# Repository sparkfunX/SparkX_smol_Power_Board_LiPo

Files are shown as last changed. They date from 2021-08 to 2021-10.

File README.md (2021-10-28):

# SparkX smôl Power Board : LiPo

SparkX smôl Power Board : LiPo (SPX-18622) (https://www.sparkfun.com/products/18622)

[*SparkX smôl Power Board : LiPo (SPX-18622)*](https://www.sparkfun.com/products/18622)

A power board for smôl:
- LiPo battery connector and charger
- Fuel gauge
- ATtiny841 for intelligent power management

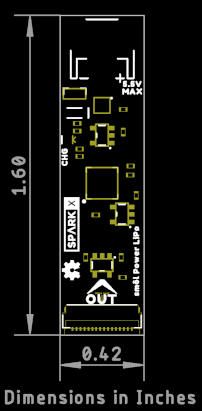
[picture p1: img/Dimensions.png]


## Repository Contents

- **/Documentation** - Datasheets etc.
- **/Hardware** - Eagle design files
- **LICENSE.md** contains the licence information

## Product Versions

- [SPX-18622](https://www.sparkfun.com/products/18622) - Original SparkX Release.

## License Information

This product is _**open source**_!

Please review the LICENSE.md file for license information.

If you have any questions or concerns on licensing, please contact technical support on our [SparkFun forums](https://forum.sparkfun.com/viewforum.php?f=123).

Distributed as-is; no warranty is given.

- Your friends at SparkFun.

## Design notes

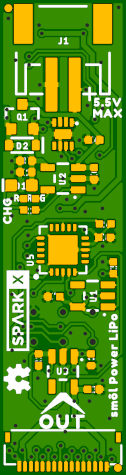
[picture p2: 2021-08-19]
img/Top.png

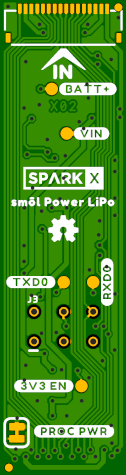
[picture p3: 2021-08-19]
img/Bottom.png

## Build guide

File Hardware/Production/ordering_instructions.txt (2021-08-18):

panel size, 193x137mm
PCB thickness, 0.8mm
number of layers, 2
soldermask color, Black
silkscreen color, White
oz copper, 1oz
finish, HASL lead free
stencils, top+bottom
pcs per panel, 48
min trace width, 0.1270mm / 0.0050in
min drill size, 0.3000mm / 0.0118in

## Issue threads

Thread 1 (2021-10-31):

Suggestions for the next board revision

PaulZC, 2021-10-31:
Based on these forum posts:

https://forum.sparkfun.com/viewtopic.php?p=229282#p229282
https://forum.sparkfun.com/viewtopic.php?p=229311#p229311

Add:
- Breakout pads for ATtiny RESET and INT0

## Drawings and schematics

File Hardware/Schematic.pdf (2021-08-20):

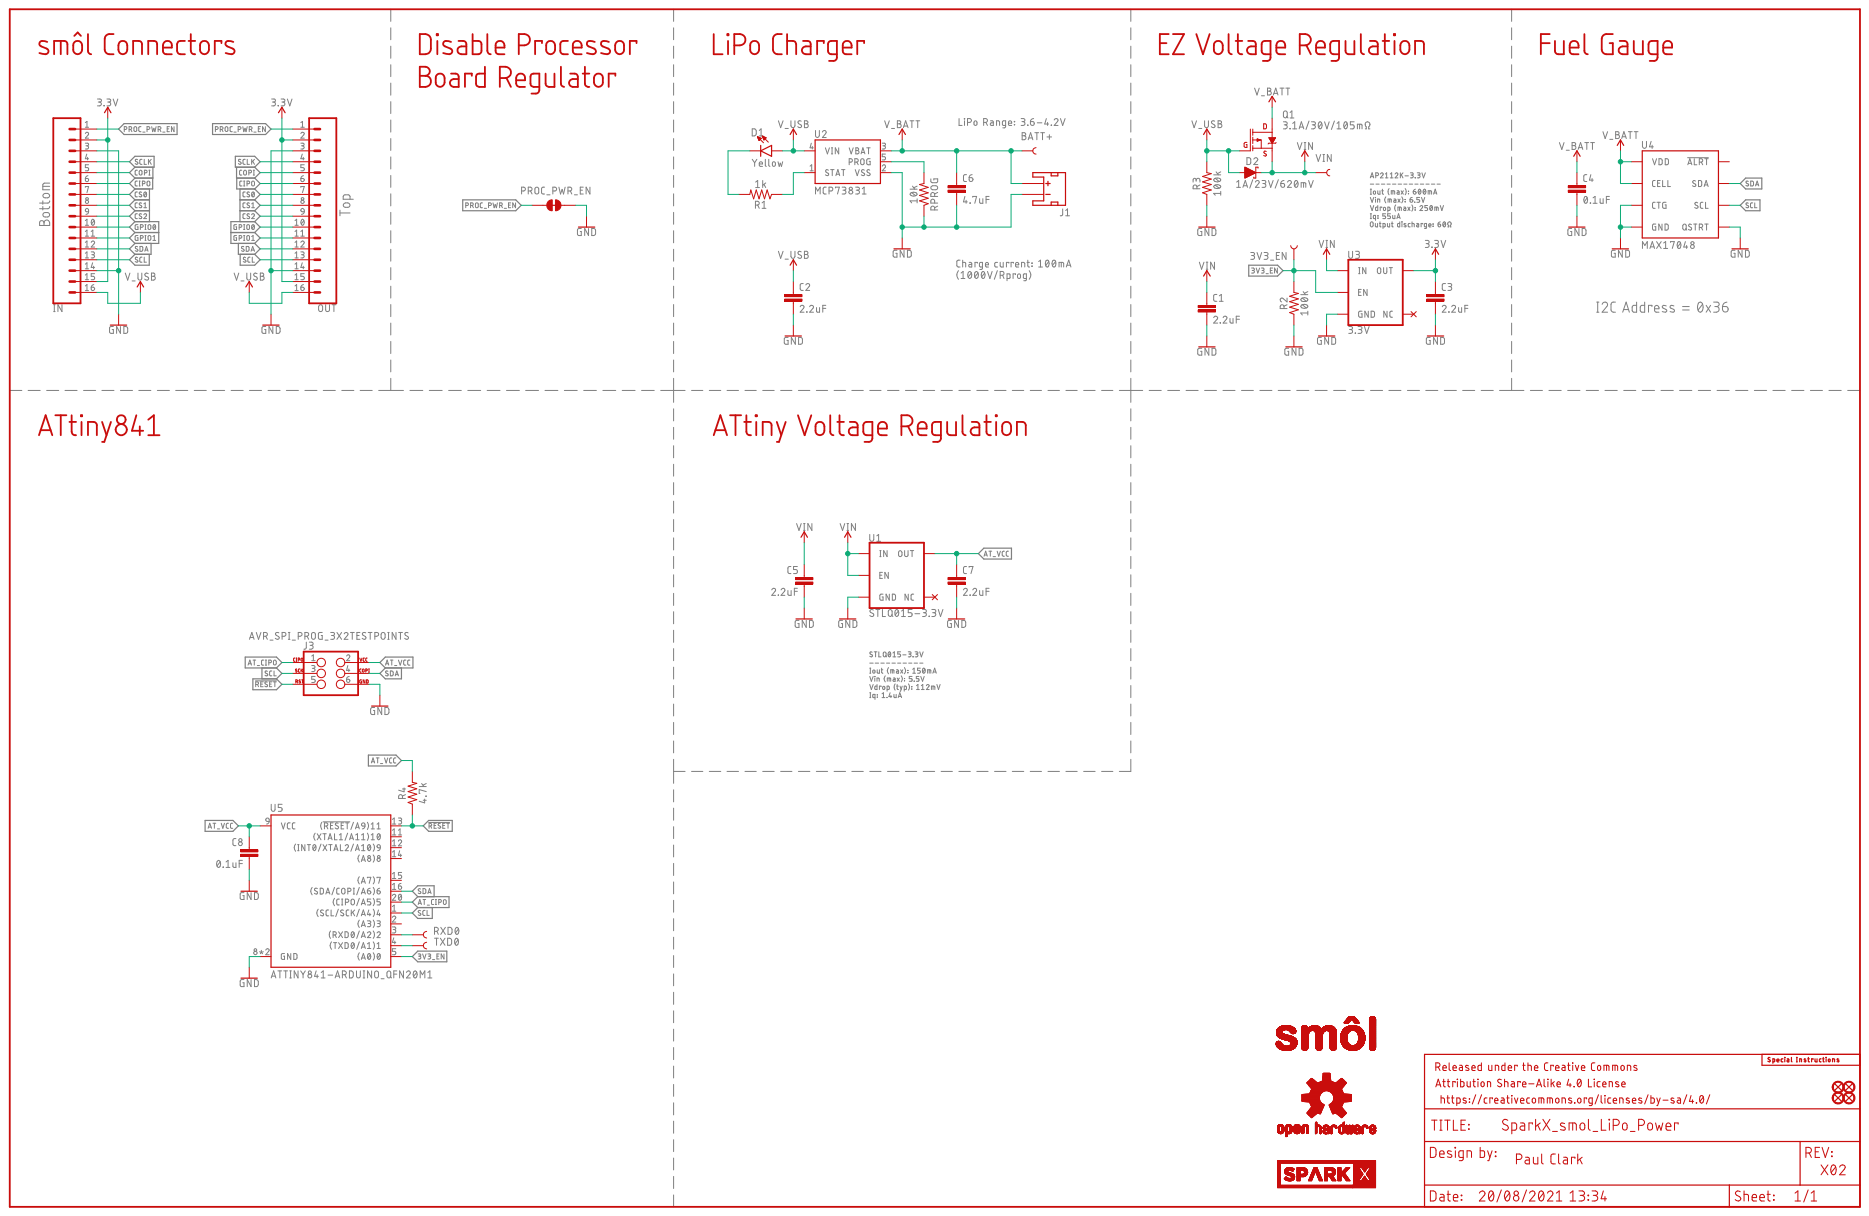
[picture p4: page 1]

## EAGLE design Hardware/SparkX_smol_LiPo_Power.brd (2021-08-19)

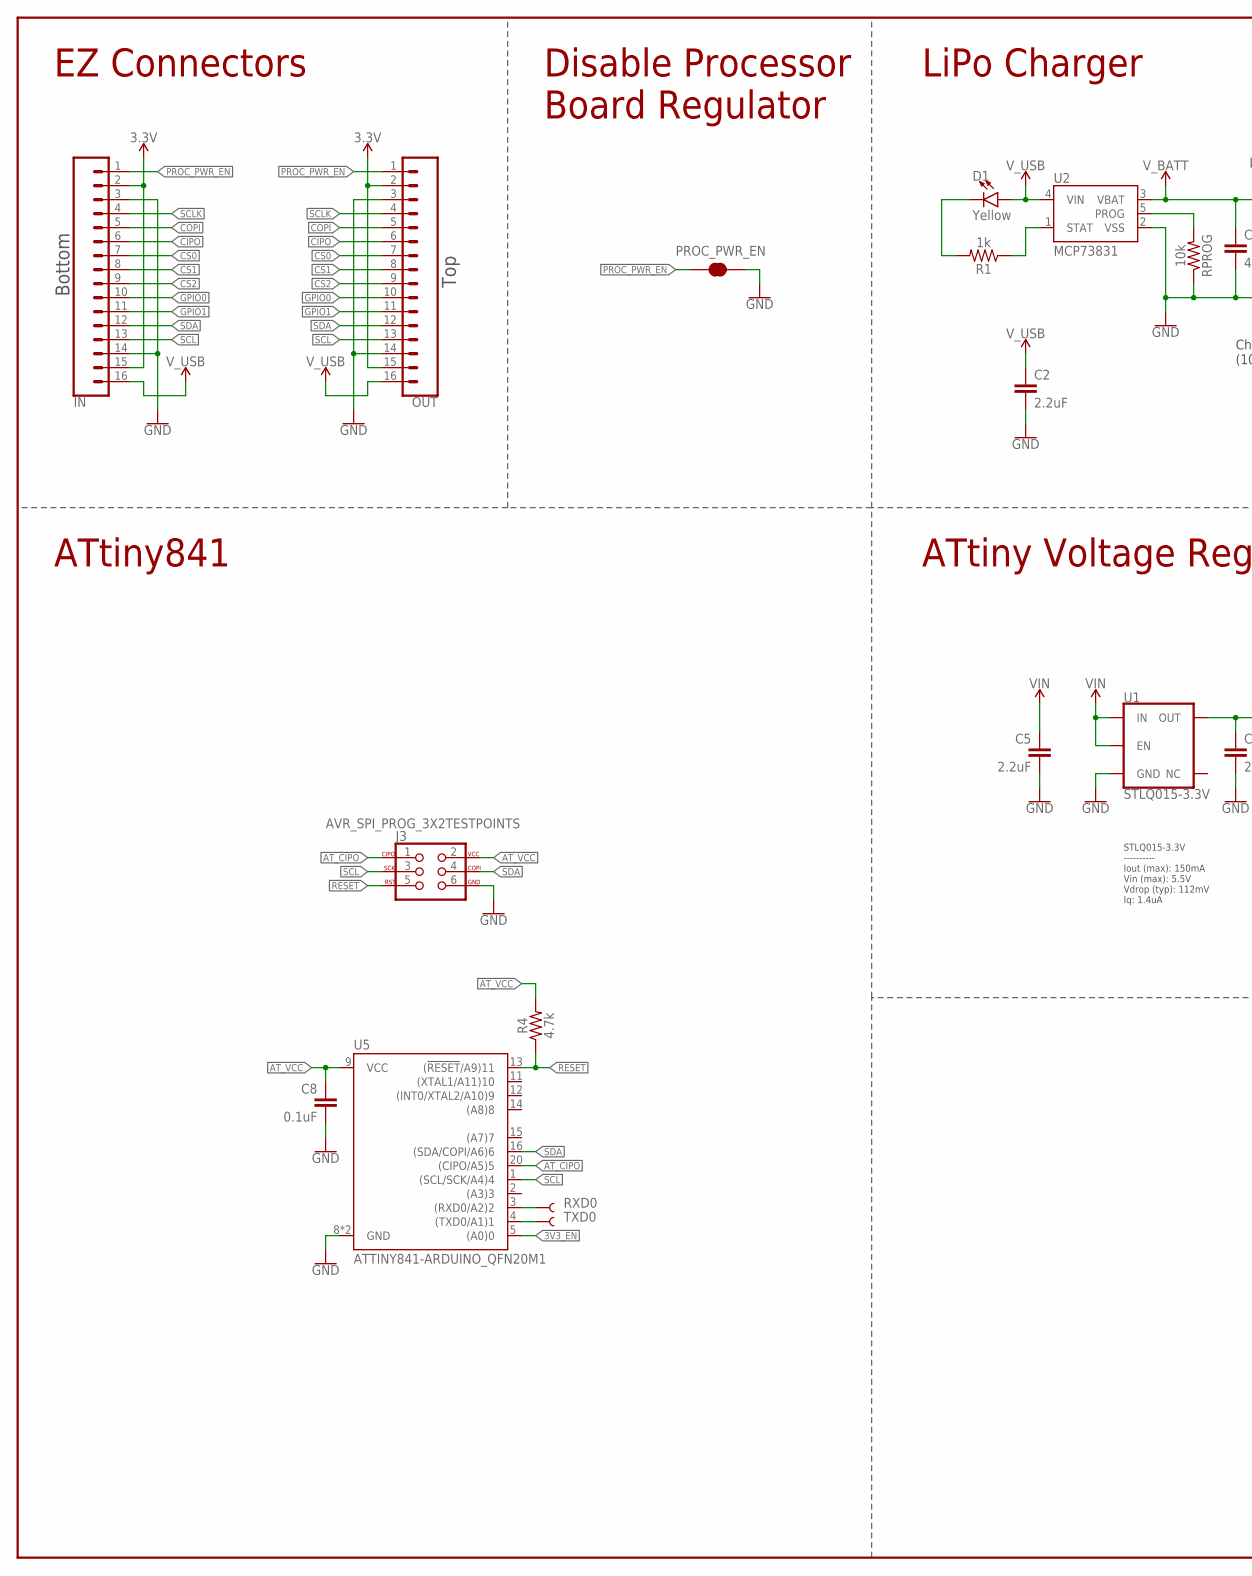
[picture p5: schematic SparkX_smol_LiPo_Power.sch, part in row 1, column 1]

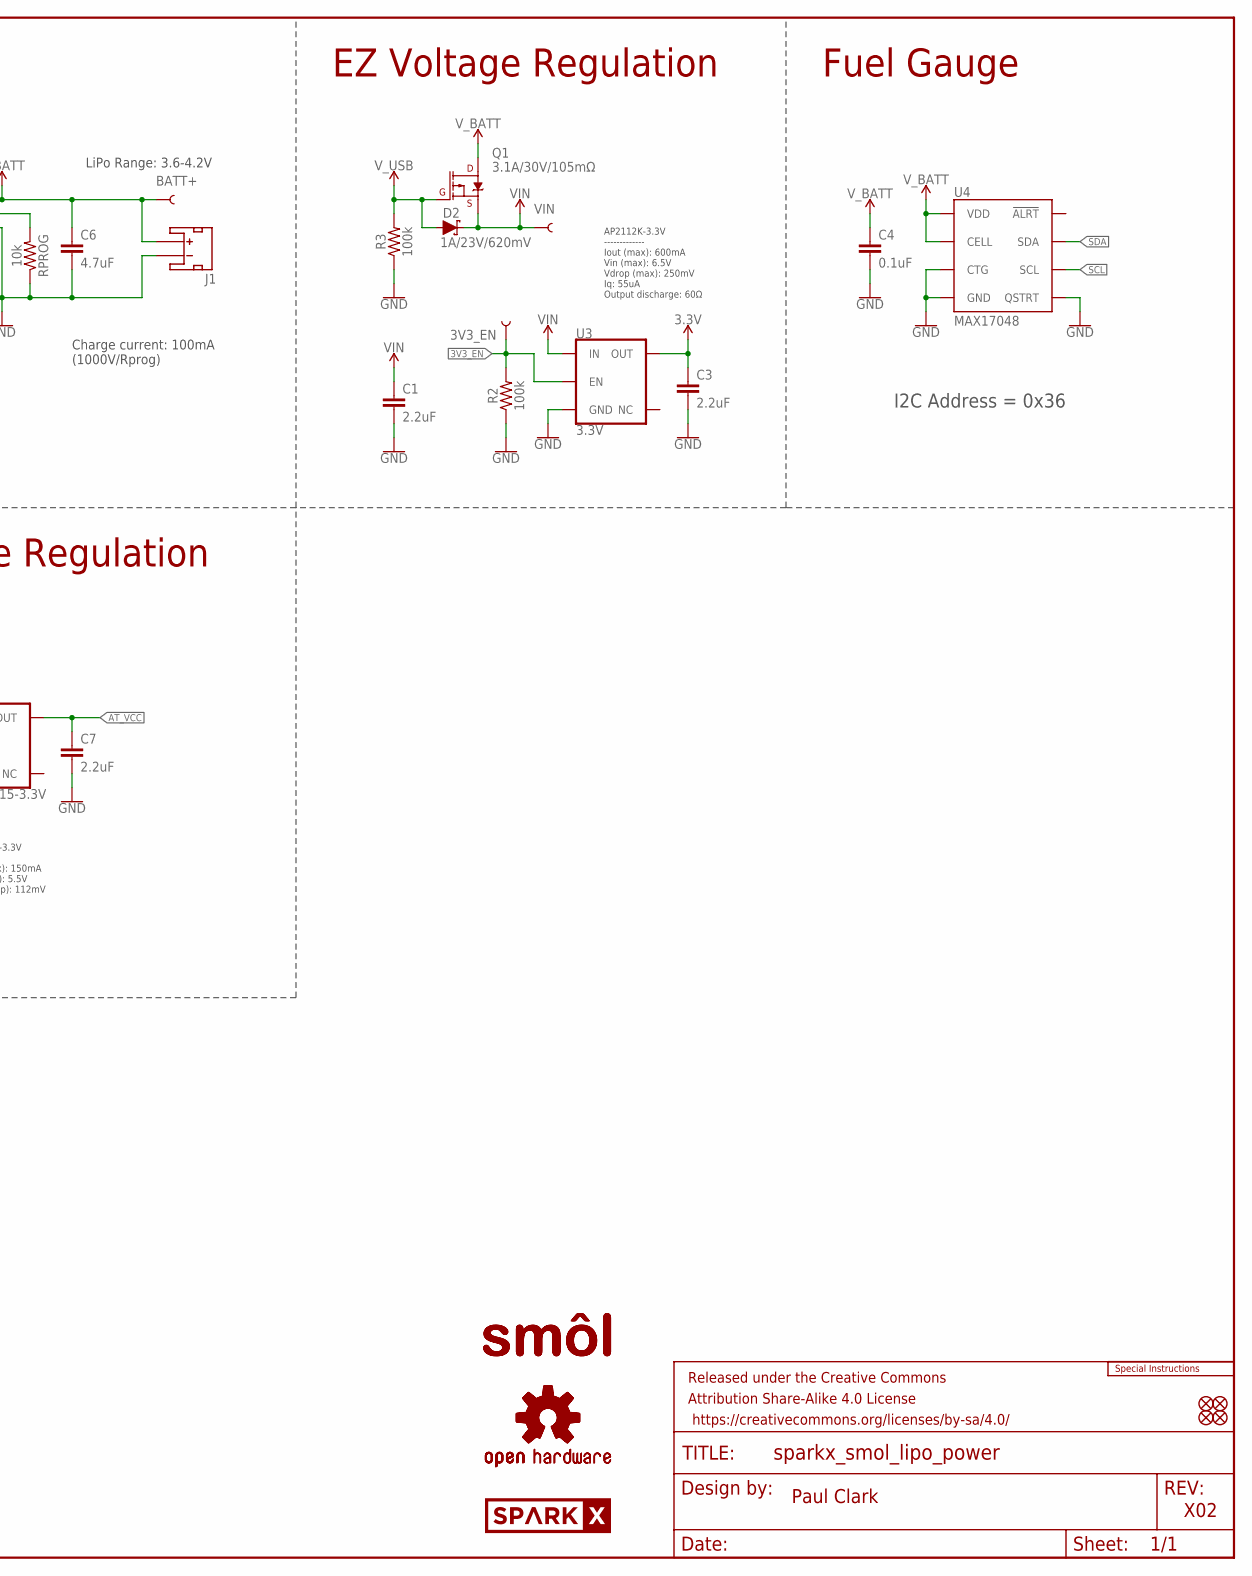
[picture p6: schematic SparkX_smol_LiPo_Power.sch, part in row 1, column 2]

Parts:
3V3_EN: TEST-POINT3X4; PAD.03X.04
BATT+: TEST-POINT3X4; PAD.03X.04
C1, C2, C3, C5, C7: 2.2uF; 0402-TIGHT
C4, C8: 0.1uF; 0402-TIGHT
C6: 4.7uF; 0402-TIGHT
D1: Yellow; LED-0603
D2: 1A/23V/620mV; SOD-323
FD1, FD2, FD3, FD4: FIDUCIALUFIDUCIAL; FIDUCIAL-MICRO
FRAME1: FRAME-LEDGER; CREATIVE_COMMONS
IN: CONN_16FPC_16_0.5MM; FPC_16_0.5MM
J1: JST_2MM_MALE; JST-2-SMD
J3: AVR_SPI_PROG_3X2TESTPOINTS; 2X3_TEST_POINTS
LOGO1: SPECIAL_INSTRUCTIONS-ORDERING; ORDERING_INSTRUCTIONS
LOGO2, LOGO3: OSHW-LOGOMINI; OSHW-LOGO-MINI
OUT: CONN_16FPC_16_0.5MM; FPC_16_0.5MM
PROC_PWR_EN: JUMPER-SMT_2_NC_TRACE_SILK; SMT-JUMPER_2_NC_TRACE_SILK
Q1: 3.1A/30V/105mΩ; SOT23-3
R1: 1k; 0402-TIGHT
R2, R3: 100k; 0402-TIGHT
R4: 4.7k; 0402-TIGHT
RPROG: 10k; 0402-TIGHT
RXD0: TEST-POINT3X4; PAD.03X.04
TXD0: TEST-POINT3X4; PAD.03X.04
U1: STLQ015-3.3V; SOT23-5
U2: MCP73831; SOT23-5
U3: 3.3V; SOT23-5
U4: MAX17048; DFN-8
U5: ATTINY841-ARDUINO_QFN20M1; QFN20_20M1
U$1: SPARKX-LOGO3; SPARKX-SMALL
U$3, U$9: SMOL_LOGOSMALL; SMOL_SMALL
VIN: TEST-POINT3X4; PAD.03X.04

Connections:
3.3V: C3.1, IN.2, IN.15, OUT.2, OUT.15, U3.5 (OUT)
3V3_EN: 3V3_EN.1, R2.2, U3.3 (EN), U5.5 ((A0)0)
!RESET!: J3.5, R4.1, U5.13 ((!RESET!/A9)11)
AT_CIPO: J3.1, U5.20 ((CIPO/A5)5)
AT_VCC: C7.1, C8.1, J3.2, R4.2, U1.5 (OUT), U5.9 (VCC)
CHG_LED: R1.1, U2.1 (STAT)
CIPO: IN.6, OUT.6
COPI: IN.5, OUT.5
CS0: IN.7, OUT.7
CS1: IN.8, OUT.8
CS2: IN.9, OUT.9
GND: C1.2, C2.2, C3.2, C4.2, C5.2, C6.2, C7.2, C8.2, IN.3, IN.14, J1.1 (-), J3.6, OUT.3, OUT.14, PROC_PWR_EN.2, R2.1, R3.1, RPROG.1, U1.2 (GND), U2.2 (VSS), U3.2 (GND), U4.1 (CTG), U4.4 (GND), U4.6 (QSTRT), U4.9 (GND), U5.8 (GND), U5.PAD (GND)
GPIO0: IN.10, OUT.10
GPIO1: IN.11, OUT.11
unnamed: RPROG.2, U2.5 (PROG)
unnamed: D1.C, R1.2
PROC_PWR_EN: IN.1, OUT.1, PROC_PWR_EN.1
RXD0: RXD0.1, U5.3 ((RXD0/A2)2)
SCL: IN.13, J3.3, OUT.13, U4.7 (SCL), U5.1 ((SCL/SCK/A4)4)
SCLK: IN.4, OUT.4
SDA: IN.12, J3.4, OUT.12, U4.8 (SDA), U5.16 ((SDA/COPI/A6)6)
TXD0: TXD0.1, U5.4 ((TXD0/A1)1)
VIN: C1.1, C5.1, D2.C, Q1.2 (S), U1.1 (IN), U1.3 (EN), U3.1 (IN), VIN.1
V_BATT: BATT+.1, C4.1, C6.1, J1.2 (+), Q1.3 (D), U2.3 (VBAT), U4.2 (CELL), U4.3 (VDD)
V_USB: C2.1, D1.A, D2.A, IN.16, OUT.16, Q1.1 (G), R3.2, U2.4 (VIN)

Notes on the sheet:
Paul Clark
X02
EZ Connectors
Top
Bottom
LiPo Charger
LiPo Range: 3.6-4.2V
Charge current: 100mA (1000V/Rprog)
EZ Voltage Regulation
Disable Processor Board Regulator
AP2112K-3.3V ------------- Iout (max): 600mA Vin (max): 6.5V Vdrop (max): 250mV Iq: 55uA Output discharge: 60Ω
Fuel Gauge
I2C Address = 0x36
ATtiny841
STLQ015-3.3V ---------- Iout (max): 150mA Vin (max): 5.5V Vdrop (typ): 112mV Iq: 1.4uA
ATtiny Voltage Regulation

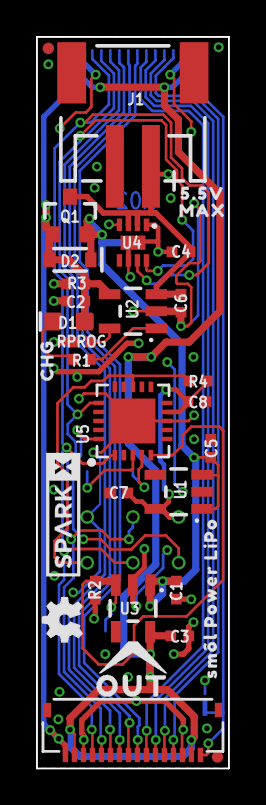
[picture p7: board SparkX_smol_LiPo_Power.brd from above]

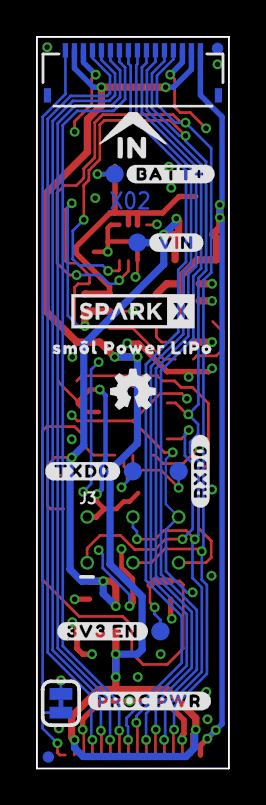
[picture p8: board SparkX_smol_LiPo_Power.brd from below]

Board: 2 copper layers, 10.7 x 40.6 mm, 56 parts (21 on the bottom side), 25 nets.

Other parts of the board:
U$2, U$18: SM�L_POWER_LIPO0
U$4: #BATT##0
U$5: #VIN#0
U$6: #3V3_EN#0
U$7: #PROC_PWR#0
U$8: IN0
U$10: CHG0
U$11: MAX0
U$14: #RXD0#0
U$15: #TXD0#0
U$16: 5#5V0
U$17: OUT0
U$20: SPARKX-LOGO3; SPARKX-SMALL

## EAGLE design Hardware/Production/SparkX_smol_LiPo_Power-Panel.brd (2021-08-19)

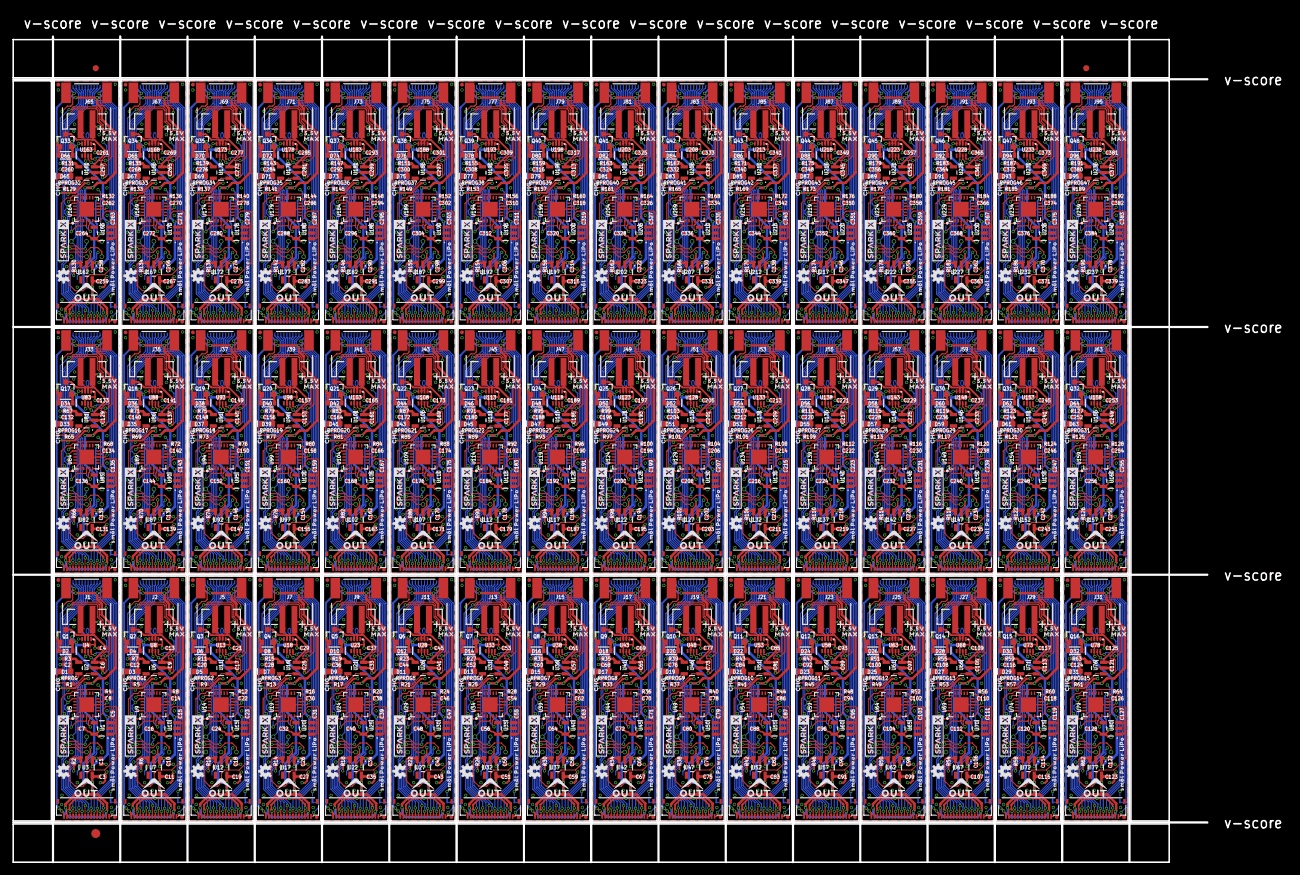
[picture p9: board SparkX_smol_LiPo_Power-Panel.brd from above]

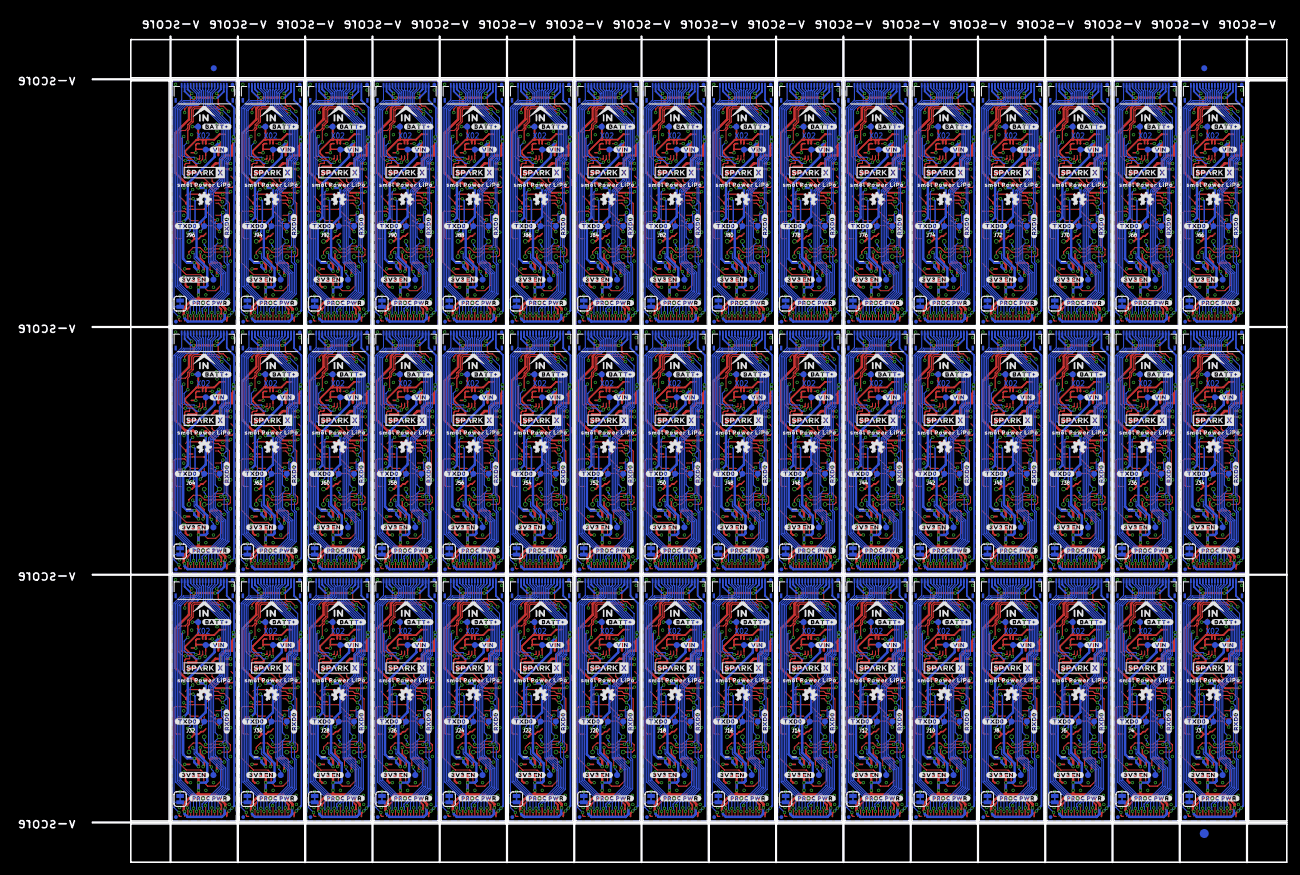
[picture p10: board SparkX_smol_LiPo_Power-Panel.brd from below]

Board: 2 copper layers, 198.4 x 137.2 mm, 2598 parts (1011 on the bottom side), 1200 nets.

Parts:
3V3_EN, 3V3_EN1, 3V3_EN2, 3V3_EN3, 3V3_EN4, 3V3_EN5, 3V3_EN6, 3V3_EN7, 3V3_EN8, 3V3_EN9, 3V3_EN10, 3V3_EN11, 3V3_EN12, 3V3_EN13, 3V3_EN14, 3V3_EN15, 3V3_EN16, 3V3_EN17, 3V3_EN18, 3V3_EN19, 3V3_EN20, 3V3_EN21, 3V3_EN22, 3V3_EN23, 3V3_EN24, 3V3_EN25, 3V3_EN26, 3V3_EN27, 3V3_EN28, 3V3_EN29, 3V3_EN30, 3V3_EN31, 3V3_EN32, 3V3_EN33, 3V3_EN34, 3V3_EN35, 3V3_EN36, 3V3_EN37, 3V3_EN38, 3V3_EN39, 3V3_EN40, 3V3_EN41, 3V3_EN42, 3V3_EN43, 3V3_EN44, 3V3_EN45, 3V3_EN46, 3V3_EN47: TEST-POINT3X4; PAD.03X.04
BATT+, BATT+1, BATT+2, BATT+3, BATT+4, BATT+5, BATT+6, BATT+7, BATT+8, BATT+9, BATT+10, BATT+11, BATT+12, BATT+13, BATT+14, BATT+15, BATT+16, BATT+17, BATT+18, BATT+19, BATT+20, BATT+21, BATT+22, BATT+23, BATT+24, BATT+25, BATT+26, BATT+27, BATT+28, BATT+29, BATT+30, BATT+31, BATT+32, BATT+33, BATT+34, BATT+35, BATT+36, BATT+37, BATT+38, BATT+39, BATT+40, BATT+41, BATT+42, BATT+43, BATT+44, BATT+45, BATT+46, BATT+47: TEST-POINT3X4; PAD.03X.04
C1, C2, C3, C5, C7, C10, C11, C12, C15, C16, C18, C19, C20, C23, C24, C26, C27, C28, C31, C32, C34, C35, C36, C39, C40, C42, C43, C44, C47, C48, C50, C51, C52, C55, C56, C58, C59, C60, C63, C64, C66, C67, C68, C71, C72, C74, C75, C76, C79, C80, C82, C83, C84, C87, C88, C90, C91, C92, C95, C96, C98, C99, C100, C103, C104, C106, C107, C108, C111, C112, C114, C115, C116, C119, C120, C122, C123, C124, C127, C128, C130, C131, C132, C135, C136, C138, C139, C140, C143, C144, C146, C147, C148, C151, C152, C154, C155, C156, C159, C160, C162, C163, C164, C167, C168, C170, C171, C172, C175, C176, C178, C179, C180, C183, C184, C186, C187, C188, C191, C192, C194, C195, C196, C199, C200, C202, C203, C204, C207, C208, C210, C211, C212, C215, C216, C218, C219, C220, C223, C224, C226, C227, C228, C231, C232, C234, C235, C236, C239, C240, C242, C243, C244, C247, C248, C250, C251, C252, C255, C256, C258, C259, C260, C263, C264, C266, C267, C268, C271, C272, C274, C275, C276, C279, C280, C282, C283, C284, C287, C288, C290, C291, C292, C295, C296, C298, C299, C300, C303, C304, C306, C307, C308, C311, C312, C314, C315, C316, C319, C320, C322, C323, C324, C327, C328, C330, C331, C332, C335, C336, C338, C339, C340, C343, C344, C346, C347, C348, C351, C352, C354, C355, C356, C359, C360, C362, C363, C364, C367, C368, C370, C371, C372, C375, C376, C378, C379, C380, C383, C384: 2.2uF; 0402-TIGHT
C4, C8, C13, C14, C21, C22, C29, C30, C37, C38, C45, C46, C53, C54, C61, C62, C69, C70, C77, C78, C85, C86, C93, C94, C101, C102, C109, C110, C117, C118, C125, C126, C133, C134, C141, C142, C149, C150, C157, C158, C165, C166, C173, C174, C181, C182, C189, C190, C197, C198, C205, C206, C213, C214, C221, C222, C229, C230, C237, C238, C245, C246, C253, C254, C261, C262, C269, C270, C277, C278, C285, C286, C293, C294, C301, C302, C309, C310, C317, C318, C325, C326, C333, C334, C341, C342, C349, C350, C357, C358, C365, C366, C373, C374, C381, C382: 0.1uF; 0402-TIGHT
C6, C9, C17, C25, C33, C41, C49, C57, C65, C73, C81, C89, C97, C105, C113, C121, C129, C137, C145, C153, C161, C169, C177, C185, C193, C201, C209, C217, C225, C233, C241, C249, C257, C265, C273, C281, C289, C297, C305, C313, C321, C329, C337, C345, C353, C361, C369, C377: 4.7uF; 0402-TIGHT
D1, D3, D5, D7, D9, D11, D13, D15, D17, D19, D21, D23, D25, D27, D29, D31, D33, D35, D37, D39, D41, D43, D45, D47, D49, D51, D53, D55, D57, D59, D61, D63, D65, D67, D69, D71, D73, D75, D77, D79, D81, D83, D85, D87, D89, D91, D93, D95: Yellow; LED-0603
D2, D4, D6, D8, D10, D12, D14, D16, D18, D20, D22, D24, D26, D28, D30, D32, D34, D36, D38, D40, D42, D44, D46, D48, D50, D52, D54, D56, D58, D60, D62, D64, D66, D68, D70, D72, D74, D76, D78, D80, D82, D84, D86, D88, D90, D92, D94, D96: 1A/23V/620mV; SOD-323
E$1, E$2, E$3, E$4: FIDUCIAL-1X2
E$5, E$6: FIDUCIAL-1.5X3
FD1, FD2, FD3, FD4, FD5, FD6, FD7, FD8, FD9, FD10, FD11, FD12, FD13, FD14, FD15, FD16, FD17, FD18, FD19, FD20, FD21, FD22, FD23, FD24, FD25, FD26, FD27, FD28, FD29, FD30, FD31, FD32, FD33, FD34, FD35, FD36, FD37, FD38, FD39, FD40, FD41, FD42, FD43, FD44, FD45, FD46, FD47, FD48, FD49, FD50, FD51, FD52, FD53, FD54, FD55, FD56, FD57, FD58, FD59, FD60, FD61, FD62, FD63, FD64, FD65, FD66, FD67, FD68, FD69, FD70, FD71, FD72, FD73, FD74, FD75, FD76, FD77, FD78, FD79, FD80, FD81, FD82, FD83, FD84, FD85, FD86, FD87, FD88, FD89, FD90, FD91, FD92, FD93, FD94, FD95, FD96, FD97, FD98, FD99, FD100, FD101, FD102, FD103, FD104, FD105, FD106, FD107, FD108, FD109, FD110, FD111, FD112, FD113, FD114, FD115, FD116, FD117, FD118, FD119, FD120, FD121, FD122, FD123, FD124, FD125, FD126, FD127, FD128, FD129, FD130, FD131, FD132, FD133, FD134, FD135, FD136, FD137, FD138, FD139, FD140, FD141, FD142, FD143, FD144, FD145, FD146, FD147, FD148, FD149, FD150, FD151, FD152, FD153, FD154, FD155, FD156, FD157, FD158, FD159, FD160, FD161, FD162, FD163, FD164, FD165, FD166, FD167, FD168, FD169, FD170, FD171, FD172, FD173, FD174, FD175, FD176, FD177, FD178, FD179, FD180, FD181, FD182, FD183, FD184, FD185, FD186, FD187, FD188, FD189, FD190, FD191, FD192: FIDUCIALUFIDUCIAL; FIDUCIAL-MICRO
IN, IN1, IN2, IN3, IN4, IN5, IN6, IN7, IN8, IN9, IN10, IN11, IN12, IN13, IN14, IN15, IN16, IN17, IN18, IN19, IN20, IN21, IN22, IN23, IN24, IN25, IN26, IN27, IN28, IN29, IN30, IN31, IN32, IN33, IN34, IN35, IN36, IN37, IN38, IN39, IN40, IN41, IN42, IN43, IN44, IN45, IN46, IN47: FPC_16_0.5MM
J1, J2, J5, J7, J9, J11, J13, J15, J17, J19, J21, J23, J25, J27, J29, J31, J33, J35, J37, J39, J41, J43, J45, J47, J49, J51, J53, J55, J57, J59, J61, J63, J65, J67, J69, J71, J73, J75, J77, J79, J81, J83, J85, J87, J89, J91, J93, J95: JST-2-SMD
J3, J4, J6, J8, J10, J12, J14, J16, J18, J20, J22, J24, J26, J28, J30, J32, J34, J36, J38, J40, J42, J44, J46, J48, J50, J52, J54, J56, J58, J60, J62, J64, J66, J68, J70, J72, J74, J76, J78, J80, J82, J84, J86, J88, J90, J92, J94, J96: AVR_SPI_PROG_3X2TESTPOINTS; 2X3_TEST_POINTS
LOGO1, LOGO2, LOGO3, LOGO4, LOGO5, LOGO6, LOGO7, LOGO8, LOGO9, LOGO10, LOGO11, LOGO12, LOGO13, LOGO14, LOGO15, LOGO16, LOGO17, LOGO18, LOGO19, LOGO20, LOGO21, LOGO22, LOGO23, LOGO24, LOGO25, LOGO26, LOGO27, LOGO28, LOGO29, LOGO30, LOGO31, LOGO32, LOGO33, LOGO34, LOGO35, LOGO36, LOGO37, LOGO38, LOGO39, LOGO40, LOGO41, LOGO42, LOGO43, LOGO44, LOGO45, LOGO46, LOGO47, LOGO48, LOGO49, LOGO50, LOGO51, LOGO52, LOGO53, LOGO54, LOGO55, LOGO56, LOGO57, LOGO58, LOGO59, LOGO60, LOGO61, LOGO62, LOGO63, LOGO64, LOGO65, LOGO66, LOGO67, LOGO68, LOGO69, LOGO70, LOGO71, LOGO72, LOGO73, LOGO74, LOGO75, LOGO76, LOGO77, LOGO78, LOGO79, LOGO80, LOGO81, LOGO82, LOGO83, LOGO84, LOGO85, LOGO86, LOGO87, LOGO88, LOGO89, LOGO90, LOGO91, LOGO92, LOGO93, LOGO94, LOGO95, LOGO96: OSHW-LOGOMINI; OSHW-LOGO-MINI
OUT, OUT1, OUT2, OUT3, OUT4, OUT5, OUT6, OUT7, OUT8, OUT9, OUT10, OUT11, OUT12, OUT13, OUT14, OUT15, OUT16, OUT17, OUT18, OUT19, OUT20, OUT21, OUT22, OUT23, OUT24, OUT25, OUT26, OUT27, OUT28, OUT29, OUT30, OUT31, OUT32, OUT33, OUT34, OUT35, OUT36, OUT37, OUT38, OUT39, OUT40, OUT41, OUT42, OUT43, OUT44, OUT45, OUT46, OUT47: FPC_16_0.5MM
PROC_PWR_EN, PROC_PWR_EN1, PROC_PWR_EN2, PROC_PWR_EN3, PROC_PWR_EN4, PROC_PWR_EN5, PROC_PWR_EN6, PROC_PWR_EN7, PROC_PWR_EN8, PROC_PWR_EN9, PROC_PWR_EN10, PROC_PWR_EN11, PROC_PWR_EN12, PROC_PWR_EN13, PROC_PWR_EN14, PROC_PWR_EN15, PROC_PWR_EN16, PROC_PWR_EN17, PROC_PWR_EN18, PROC_PWR_EN19, PROC_PWR_EN20, PROC_PWR_EN21, PROC_PWR_EN22, PROC_PWR_EN23, PROC_PWR_EN24, PROC_PWR_EN25, PROC_PWR_EN26, PROC_PWR_EN27, PROC_PWR_EN28, PROC_PWR_EN29, PROC_PWR_EN30, PROC_PWR_EN31, PROC_PWR_EN32, PROC_PWR_EN33, PROC_PWR_EN34, PROC_PWR_EN35, PROC_PWR_EN36, PROC_PWR_EN37, PROC_PWR_EN38, PROC_PWR_EN39, PROC_PWR_EN40, PROC_PWR_EN41, PROC_PWR_EN42, PROC_PWR_EN43, PROC_PWR_EN44, PROC_PWR_EN45, PROC_PWR_EN46, PROC_PWR_EN47: JUMPER-SMT_2_NC_TRACE_SILK; SMT-JUMPER_2_NC_TRACE_SILK
Q1, Q2, Q3, Q4, Q5, Q6, Q7, Q8, Q9, Q10, Q11, Q12, Q13, Q14, Q15, Q16, Q17, Q18, Q19, Q20, Q21, Q22, Q23, Q24, Q25, Q26, Q27, Q28, Q29, Q30, Q31, Q32, Q33, Q34, Q35, Q36, Q37, Q38, Q39, Q40, Q41, Q42, Q43, Q44, Q45, Q46, Q47, Q48: 3.1A/30V/105mΩ; SOT23-3
R1, R5, R9, R13, R17, R21, R25, R29, R33, R37, R41, R45, R49, R53, R57, R61, R65, R69, R73, R77, R81, R85, R89, R93, R97, R101, R105, R109, R113, R117, R121, R125, R129, R133, R137, R141, R145, R149, R153, R157, R161, R165, R169, R173, R177, R181, R185, R189: 1k; 0402-TIGHT
R2, R3, R6, R7, R10, R11, R14, R15, R18, R19, R22, R23, R26, R27, R30, R31, R34, R35, R38, R39, R42, R43, R46, R47, R50, R51, R54, R55, R58, R59, R62, R63, R66, R67, R70, R71, R74, R75, R78, R79, R82, R83, R86, R87, R90, R91, R94, R95, R98, R99, R102, R103, R106, R107, R110, R111, R114, R115, R118, R119, R122, R123, R126, R127, R130, R131, R134, R135, R138, R139, R142, R143, R146, R147, R150, R151, R154, R155, R158, R159, R162, R163, R166, R167, R170, R171, R174, R175, R178, R179, R182, R183, R186, R187, R190, R191: 100k; 0402-TIGHT
R4, R8, R12, R16, R20, R24, R28, R32, R36, R40, R44, R48, R52, R56, R60, R64, R68, R72, R76, R80, R84, R88, R92, R96, R100, R104, R108, R112, R116, R120, R124, R128, R132, R136, R140, R144, R148, R152, R156, R160, R164, R168, R172, R176, R180, R184, R188, R192: 4.7k; 0402-TIGHT
RPROG, RPROG1, RPROG2, RPROG3, RPROG4, RPROG5, RPROG6, RPROG7, RPROG8, RPROG9, RPROG10, RPROG11, RPROG12, RPROG13, RPROG14, RPROG15, RPROG16, RPROG17, RPROG18, RPROG19, RPROG20, RPROG21, RPROG22, RPROG23, RPROG24, RPROG25, RPROG26, RPROG27, RPROG28, RPROG29, RPROG30, RPROG31, RPROG32, RPROG33, RPROG34, RPROG35, RPROG36, RPROG37, RPROG38, RPROG39, RPROG40, RPROG41, RPROG42, RPROG43, RPROG44, RPROG45, RPROG46, RPROG47: 10k; 0402-TIGHT
RXD0, RXD1, RXD2, RXD3, RXD4, RXD5, RXD6, RXD7, RXD8, RXD9, RXD10, RXD11, RXD12, RXD13, RXD14, RXD15, RXD16, RXD17, RXD18, RXD19, RXD20, RXD21, RXD22, RXD23, RXD24, RXD25, RXD26, RXD27, RXD28, RXD29, RXD30, RXD31, RXD32, RXD33, RXD34, RXD35, RXD36, RXD37, RXD38, RXD39, RXD40, RXD41, RXD42, RXD43, RXD44, RXD45, RXD46, RXD47: TEST-POINT3X4; PAD.03X.04
TXD0, TXD1, TXD2, TXD3, TXD4, TXD5, TXD6, TXD7, TXD8, TXD9, TXD10, TXD11, TXD12, TXD13, TXD14, TXD15, TXD16, TXD17, TXD18, TXD19, TXD20, TXD21, TXD22, TXD23, TXD24, TXD25, TXD26, TXD27, TXD28, TXD29, TXD30, TXD31, TXD32, TXD33, TXD34, TXD35, TXD36, TXD37, TXD38, TXD39, TXD40, TXD41, TXD42, TXD43, TXD44, TXD45, TXD46, TXD47: TEST-POINT3X4; PAD.03X.04
U1, U10, U15, U20, U25, U30, U35, U40, U45, U50, U55, U60, U65, U70, U75, U80, U85, U90, U95, U100, U105, U110, U115, U120, U125, U130, U135, U140, U145, U150, U155, U160, U165, U170, U175, U180, U185, U190, U195, U200, U205, U210, U215, U220, U225, U230, U235, U240: STLQ015-3.3V; SOT23-5
U2, U6, U11, U16, U21, U26, U31, U36, U41, U46, U51, U56, U61, U66, U71, U76, U81, U86, U91, U96, U101, U106, U111, U116, U121, U126, U131, U136, U141, U146, U151, U156, U161, U166, U171, U176, U181, U186, U191, U196, U201, U206, U211, U216, U221, U226, U231, U236: MCP73831; SOT23-5
U3, U7, U12, U17, U22, U27, U32, U37, U42, U47, U52, U57, U62, U67, U72, U77, U82, U87, U92, U97, U102, U107, U112, U117, U122, U127, U132, U137, U142, U147, U152, U157, U162, U167, U172, U177, U182, U187, U192, U197, U202, U207, U212, U217, U222, U227, U232, U237: 3.3V; SOT23-5
U4, U8, U13, U18, U23, U28, U33, U38, U43, U48, U53, U58, U63, U68, U73, U78, U83, U88, U93, U98, U103, U108, U113, U118, U123, U128, U133, U138, U143, U148, U153, U158, U163, U168, U173, U178, U183, U188, U193, U198, U203, U208, U213, U218, U223, U228, U233, U238: MAX17048; DFN-8
U5, U9, U14, U19, U24, U29, U34, U39, U44, U49, U54, U59, U64, U69, U74, U79, U84, U89, U94, U99, U104, U109, U114, U119, U124, U129, U134, U139, U144, U149, U154, U159, U164, U169, U174, U179, U184, U189, U194, U199, U204, U209, U214, U219, U224, U229, U234, U239: ATTINY841-ARDUINO_QFN20M1; QFN20_20M1
U$1, U$12, U$13, U$20, U$35, U$36, U$52, U$53, U$69, U$70, U$86, U$87, U$103, U$104, U$120, U$121, U$137, U$138, U$154, U$155, U$171, U$172, U$188, U$189, U$205, U$206, U$222, U$223, U$239, U$240, U$256, U$257, U$273, U$274, U$290, U$291, U$307, U$308, U$324, U$325, U$341, U$342, U$358, U$359, U$375, U$376, U$392, U$393, U$409, U$410, U$426, U$427, U$443, U$444, U$460, U$461, U$477, U$478, U$494, U$495, U$511, U$512, U$528, U$529, U$545, U$546, U$562, U$563, U$579, U$580, U$596, U$597, U$613, U$614, U$630, U$631, U$647, U$648, U$664, U$665, U$681, U$682, U$698, U$699, U$715, U$716, U$732, U$733, U$749, U$750, U$766, U$767, U$783, U$784, U$800, U$801: SPARKX-LOGO3; SPARKX-SMALL
U$2, U$18, U$31, U$32, U$48, U$49, U$65, U$66, U$82, U$83, U$99, U$100, U$116, U$117, U$133, U$134, U$150, U$151, U$167, U$168, U$184, U$185, U$201, U$202, U$218, U$219, U$235, U$236, U$252, U$253, U$269, U$270, U$286, U$287, U$303, U$304, U$320, U$321, U$337, U$338, U$354, U$355, U$371, U$372, U$388, U$389, U$405, U$406, U$422, U$423, U$439, U$440, U$456, U$457, U$473, U$474, U$490, U$491, U$507, U$508, U$524, U$525, U$541, U$542, U$558, U$559, U$575, U$576, U$592, U$593, U$609, U$610, U$626, U$627, U$643, U$644, U$660, U$661, U$677, U$678, U$694, U$695, U$711, U$712, U$728, U$729, U$745, U$746, U$762, U$763, U$779, U$780, U$796, U$797, U$813, U$814: SM�L_POWER_LIPO0
U$3, U$9, U$33, U$34, U$50, U$51, U$67, U$68, U$84, U$85, U$101, U$102, U$118, U$119, U$135, U$136, U$152, U$153, U$169, U$170, U$186, U$187, U$203, U$204, U$220, U$221, U$237, U$238, U$254, U$255, U$271, U$272, U$288, U$289, U$305, U$306, U$322, U$323, U$339, U$340, U$356, U$357, U$373, U$374, U$390, U$391, U$407, U$408, U$424, U$425, U$441, U$442, U$458, U$459, U$475, U$476, U$492, U$493, U$509, U$510, U$526, U$527, U$543, U$544, U$560, U$561, U$577, U$578, U$594, U$595, U$611, U$612, U$628, U$629, U$645, U$646, U$662, U$663, U$679, U$680, U$696, U$697, U$713, U$714, U$730, U$731, U$747, U$748, U$764, U$765, U$781, U$782, U$798, U$799, U$815, U$816: SMOL_LOGOSMALL; SMOL_SMALL
U$4, U$19, U$37, U$54, U$71, U$88, U$105, U$122, U$139, U$156, U$173, U$190, U$207, U$224, U$241, U$258, U$275, U$292, U$309, U$326, U$343, U$360, U$377, U$394, U$411, U$428, U$445, U$462, U$479, U$496, U$513, U$530, U$547, U$564, U$581, U$598, U$615, U$632, U$649, U$666, U$683, U$700, U$717, U$734, U$751, U$768, U$785, U$802: #BATT##0
U$5, U$21, U$38, U$55, U$72, U$89, U$106, U$123, U$140, U$157, U$174, U$191, U$208, U$225, U$242, U$259, U$276, U$293, U$310, U$327, U$344, U$361, U$378, U$395, U$412, U$429, U$446, U$463, U$480, U$497, U$514, U$531, U$548, U$565, U$582, U$599, U$616, U$633, U$650, U$667, U$684, U$701, U$718, U$735, U$752, U$769, U$786, U$803: #VIN#0
U$6, U$22, U$39, U$56, U$73, U$90, U$107, U$124, U$141, U$158, U$175, U$192, U$209, U$226, U$243, U$260, U$277, U$294, U$311, U$328, U$345, U$362, U$379, U$396, U$413, U$430, U$447, U$464, U$481, U$498, U$515, U$532, U$549, U$566, U$583, U$600, U$617, U$634, U$651, U$668, U$685, U$702, U$719, U$736, U$753, U$770, U$787, U$804: #3V3_EN#0
U$7, U$23, U$40, U$57, U$74, U$91, U$108, U$125, U$142, U$159, U$176, U$193, U$210, U$227, U$244, U$261, U$278, U$295, U$312, U$329, U$346, U$363, U$380, U$397, U$414, U$431, U$448, U$465, U$482, U$499, U$516, U$533, U$550, U$567, U$584, U$601, U$618, U$635, U$652, U$669, U$686, U$703, U$720, U$737, U$754, U$771, U$788, U$805: #PROC_PWR#0
U$8, U$29, U$46, U$63, U$80, U$97, U$114, U$131, U$148, U$165, U$182, U$199, U$216, U$233, U$250, U$267, U$284, U$301, U$318, U$335, U$352, U$369, U$386, U$403, U$420, U$437, U$454, U$471, U$488, U$505, U$522, U$539, U$556, U$573, U$590, U$607, U$624, U$641, U$658, U$675, U$692, U$709, U$726, U$743, U$760, U$777, U$794, U$811: IN0
U$10, U$24, U$41, U$58, U$75, U$92, U$109, U$126, U$143, U$160, U$177, U$194, U$211, U$228, U$245, U$262, U$279, U$296, U$313, U$330, U$347, U$364, U$381, U$398, U$415, U$432, U$449, U$466, U$483, U$500, U$517, U$534, U$551, U$568, U$585, U$602, U$619, U$636, U$653, U$670, U$687, U$704, U$721, U$738, U$755, U$772, U$789, U$806: CHG0
U$11, U$28, U$45, U$62, U$79, U$96, U$113, U$130, U$147, U$164, U$181, U$198, U$215, U$232, U$249, U$266, U$283, U$300, U$317, U$334, U$351, U$368, U$385, U$402, U$419, U$436, U$453, U$470, U$487, U$504, U$521, U$538, U$555, U$572, U$589, U$606, U$623, U$640, U$657, U$674, U$691, U$708, U$725, U$742, U$759, U$776, U$793, U$810: MAX0
U$14, U$25, U$42, U$59, U$76, U$93, U$110, U$127, U$144, U$161, U$178, U$195, U$212, U$229, U$246, U$263, U$280, U$297, U$314, U$331, U$348, U$365, U$382, U$399, U$416, U$433, U$450, U$467, U$484, U$501, U$518, U$535, U$552, U$569, U$586, U$603, U$620, U$637, U$654, U$671, U$688, U$705, U$722, U$739, U$756, U$773, U$790, U$807: #RXD0#0
U$15, U$26, U$43, U$60, U$77, U$94, U$111, U$128, U$145, U$162, U$179, U$196, U$213, U$230, U$247, U$264, U$281, U$298, U$315, U$332, U$349, U$366, U$383, U$400, U$417, U$434, U$451, U$468, U$485, U$502, U$519, U$536, U$553, U$570, U$587, U$604, U$621, U$638, U$655, U$672, U$689, U$706, U$723, U$740, U$757, U$774, U$791, U$808: #TXD0#0
U$16, U$27, U$44, U$61, U$78, U$95, U$112, U$129, U$146, U$163, U$180, U$197, U$214, U$231, U$248, U$265, U$282, U$299, U$316, U$333, U$350, U$367, U$384, U$401, U$418, U$435, U$452, U$469, U$486, U$503, U$520, U$537, U$554, U$571, U$588, U$605, U$622, U$639, U$656, U$673, U$690, U$707, U$724, U$741, U$758, U$775, U$792, U$809: 5#5V0
U$17, U$30, U$47, U$64, U$81, U$98, U$115, U$132, U$149, U$166, U$183, U$200, U$217, U$234, U$251, U$268, U$285, U$302, U$319, U$336, U$353, U$370, U$387, U$404, U$421, U$438, U$455, U$472, U$489, U$506, U$523, U$540, U$557, U$574, U$591, U$608, U$625, U$642, U$659, U$676, U$693, U$710, U$727, U$744, U$761, U$778, U$795, U$812: OUT0
VIN, VIN1, VIN2, VIN3, VIN4, VIN5, VIN6, VIN7, VIN8, VIN9, VIN10, VIN11, VIN12, VIN13, VIN14, VIN15, VIN16, VIN17, VIN18, VIN19, VIN20, VIN21, VIN22, VIN23, VIN24, VIN25, VIN26, VIN27, VIN28, VIN29, VIN30, VIN31, VIN32, VIN33, VIN34, VIN35, VIN36, VIN37, VIN38, VIN39, VIN40, VIN41, VIN42, VIN43, VIN44, VIN45, VIN46, VIN47: TEST-POINT3X4; PAD.03X.04

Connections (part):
3.3V: C3.1, IN.2, IN.15, OUT.2, OUT.15, U3.5
3.3V1: C11.1, IN1.2, IN1.15, OUT1.2, OUT1.15, U7.5
3.3V2: C19.1, IN2.2, IN2.15, OUT2.2, OUT2.15, U12.5
3.3V3: C27.1, IN3.2, IN3.15, OUT3.2, OUT3.15, U17.5
3.3V4: C35.1, IN4.2, IN4.15, OUT4.2, OUT4.15, U22.5
3.3V5: C43.1, IN5.2, IN5.15, OUT5.2, OUT5.15, U27.5
3.3V6: C51.1, IN6.2, IN6.15, OUT6.2, OUT6.15, U32.5
3.3V7: C59.1, IN7.2, IN7.15, OUT7.2, OUT7.15, U37.5
3.3V8: C67.1, IN8.2, IN8.15, OUT8.2, OUT8.15, U42.5
3.3V9: C75.1, IN9.2, IN9.15, OUT9.2, OUT9.15, U47.5
3.3V10: C83.1, IN10.2, IN10.15, OUT10.2, OUT10.15, U52.5
3.3V11: C91.1, IN11.2, IN11.15, OUT11.2, OUT11.15, U57.5
3.3V12: C99.1, IN12.2, IN12.15, OUT12.2, OUT12.15, U62.5
3.3V13: C107.1, IN13.2, IN13.15, OUT13.2, OUT13.15, U67.5
3.3V14: C115.1, IN14.2, IN14.15, OUT14.2, OUT14.15, U72.5
3.3V15: C123.1, IN15.2, IN15.15, OUT15.2, OUT15.15, U77.5
3.3V16: C131.1, IN16.2, IN16.15, OUT16.2, OUT16.15, U82.5
3.3V17: C139.1, IN17.2, IN17.15, OUT17.2, OUT17.15, U87.5
3.3V18: C147.1, IN18.2, IN18.15, OUT18.2, OUT18.15, U92.5
3.3V19: C155.1, IN19.2, IN19.15, OUT19.2, OUT19.15, U97.5
3.3V20: C163.1, IN20.2, IN20.15, OUT20.2, OUT20.15, U102.5
3.3V21: C171.1, IN21.2, IN21.15, OUT21.2, OUT21.15, U107.5
3.3V22: C179.1, IN22.2, IN22.15, OUT22.2, OUT22.15, U112.5
3.3V23: C187.1, IN23.2, IN23.15, OUT23.2, OUT23.15, U117.5
3.3V24: C195.1, IN24.2, IN24.15, OUT24.2, OUT24.15, U122.5
3.3V25: C203.1, IN25.2, IN25.15, OUT25.2, OUT25.15, U127.5
3.3V26: C211.1, IN26.2, IN26.15, OUT26.2, OUT26.15, U132.5
3.3V27: C219.1, IN27.2, IN27.15, OUT27.2, OUT27.15, U137.5
3.3V28: C227.1, IN28.2, IN28.15, OUT28.2, OUT28.15, U142.5
3.3V29: C235.1, IN29.2, IN29.15, OUT29.2, OUT29.15, U147.5
3.3V30: C243.1, IN30.2, IN30.15, OUT30.2, OUT30.15, U152.5
3.3V31: C251.1, IN31.2, IN31.15, OUT31.2, OUT31.15, U157.5
3.3V32: C259.1, IN32.2, IN32.15, OUT32.2, OUT32.15, U162.5
3.3V33: C267.1, IN33.2, IN33.15, OUT33.2, OUT33.15, U167.5
3.3V34: C275.1, IN34.2, IN34.15, OUT34.2, OUT34.15, U172.5
3.3V35: C283.1, IN35.2, IN35.15, OUT35.2, OUT35.15, U177.5
3.3V36: C291.1, IN36.2, IN36.15, OUT36.2, OUT36.15, U182.5
3.3V37: C299.1, IN37.2, IN37.15, OUT37.2, OUT37.15, U187.5
3.3V38: C307.1, IN38.2, IN38.15, OUT38.2, OUT38.15, U192.5
3.3V39: C315.1, IN39.2, IN39.15, OUT39.2, OUT39.15, U197.5
3.3V40: C323.1, IN40.2, IN40.15, OUT40.2, OUT40.15, U202.5
3.3V41: C331.1, IN41.2, IN41.15, OUT41.2, OUT41.15, U207.5
3.3V42: C339.1, IN42.2, IN42.15, OUT42.2, OUT42.15, U212.5
3.3V43: C347.1, IN43.2, IN43.15, OUT43.2, OUT43.15, U217.5
3.3V44: C355.1, IN44.2, IN44.15, OUT44.2, OUT44.15, U222.5
3.3V45: C363.1, IN45.2, IN45.15, OUT45.2, OUT45.15, U227.5
3.3V46: C371.1, IN46.2, IN46.15, OUT46.2, OUT46.15, U232.5
3.3V47: C379.1, IN47.2, IN47.15, OUT47.2, OUT47.15, U237.5
3V3_EN: 3V3_EN.1, R2.2, U3.3, U5.5
3V3_EN1: 3V3_EN1.1, R6.2, U7.3, U9.5
3V3_EN2: 3V3_EN2.1, R10.2, U12.3, U14.5
3V3_EN3: 3V3_EN3.1, R14.2, U17.3, U19.5
3V3_EN4: 3V3_EN4.1, R18.2, U22.3, U24.5
3V3_EN5: 3V3_EN5.1, R22.2, U27.3, U29.5
3V3_EN6: 3V3_EN6.1, R26.2, U32.3, U34.5
3V3_EN7: 3V3_EN7.1, R30.2, U37.3, U39.5
3V3_EN8: 3V3_EN8.1, R34.2, U42.3, U44.5
3V3_EN9: 3V3_EN9.1, R38.2, U47.3, U49.5
3V3_EN10: 3V3_EN10.1, R42.2, U52.3, U54.5
3V3_EN11: 3V3_EN11.1, R46.2, U57.3, U59.5
3V3_EN12: 3V3_EN12.1, R50.2, U62.3, U64.5
3V3_EN13: 3V3_EN13.1, R54.2, U67.3, U69.5
3V3_EN14: 3V3_EN14.1, R58.2, U72.3, U74.5
3V3_EN15: 3V3_EN15.1, R62.2, U77.3, U79.5
3V3_EN16: 3V3_EN16.1, R66.2, U82.3, U84.5
3V3_EN17: 3V3_EN17.1, R70.2, U87.3, U89.5
3V3_EN18: 3V3_EN18.1, R74.2, U92.3, U94.5
3V3_EN19: 3V3_EN19.1, R78.2, U97.3, U99.5
3V3_EN20: 3V3_EN20.1, R82.2, U102.3, U104.5
3V3_EN21: 3V3_EN21.1, R86.2, U107.3, U109.5
3V3_EN22: 3V3_EN22.1, R90.2, U112.3, U114.5
3V3_EN23: 3V3_EN23.1, R94.2, U117.3, U119.5
3V3_EN24: 3V3_EN24.1, R98.2, U122.3, U124.5
3V3_EN25: 3V3_EN25.1, R102.2, U127.3, U129.5
3V3_EN26: 3V3_EN26.1, R106.2, U132.3, U134.5
3V3_EN27: 3V3_EN27.1, R110.2, U137.3, U139.5
3V3_EN28: 3V3_EN28.1, R114.2, U142.3, U144.5
3V3_EN29: 3V3_EN29.1, R118.2, U147.3, U149.5
3V3_EN30: 3V3_EN30.1, R122.2, U152.3, U154.5
3V3_EN31: 3V3_EN31.1, R126.2, U157.3, U159.5
3V3_EN32: 3V3_EN32.1, R130.2, U162.3, U164.5
3V3_EN33: 3V3_EN33.1, R134.2, U167.3, U169.5
3V3_EN34: 3V3_EN34.1, R138.2, U172.3, U174.5
3V3_EN35: 3V3_EN35.1, R142.2, U177.3, U179.5
3V3_EN36: 3V3_EN36.1, R146.2, U182.3, U184.5
3V3_EN37: 3V3_EN37.1, R150.2, U187.3, U189.5
3V3_EN38: 3V3_EN38.1, R154.2, U192.3, U194.5
3V3_EN39: 3V3_EN39.1, R158.2, U197.3, U199.5
3V3_EN40: 3V3_EN40.1, R162.2, U202.3, U204.5
3V3_EN41: 3V3_EN41.1, R166.2, U207.3, U209.5
3V3_EN42: 3V3_EN42.1, R170.2, U212.3, U214.5
3V3_EN43: 3V3_EN43.1, R174.2, U217.3, U219.5
3V3_EN44: 3V3_EN44.1, R178.2, U222.3, U224.5
3V3_EN45: 3V3_EN45.1, R182.2, U227.3, U229.5
3V3_EN46: 3V3_EN46.1, R186.2, U232.3, U234.5
3V3_EN47: 3V3_EN47.1, R190.2, U237.3, U239.5
!RESET!: J3.5, R4.1, U5.13
!RESET!1: J4.5, R8.1, U9.13
!RESET!2: J6.5, R12.1, U14.13
!RESET!3: J8.5, R16.1, U19.13
!RESET!4: J10.5, R20.1, U24.13
!RESET!5: J12.5, R24.1, U29.13
!RESET!6: J14.5, R28.1, U34.13
!RESET!7: J16.5, R32.1, U39.13
!RESET!8: J18.5, R36.1, U44.13
!RESET!9: J20.5, R40.1, U49.13
!RESET!10: J22.5, R44.1, U54.13
!RESET!11: J24.5, R48.1, U59.13
!RESET!12: J26.5, R52.1, U64.13
!RESET!13: J28.5, R56.1, U69.13
!RESET!14: J30.5, R60.1, U74.13
!RESET!15: J32.5, R64.1, U79.13
!RESET!16: J34.5, R68.1, U84.13
!RESET!17: J36.5, R72.1, U89.13
!RESET!18: J38.5, R76.1, U94.13
!RESET!19: J40.5, R80.1, U99.13
!RESET!20: J42.5, R84.1, U104.13
!RESET!21: J44.5, R88.1, U109.13
!RESET!22: J46.5, R92.1, U114.13
!RESET!23: J48.5, R96.1, U119.13
!RESET!24: J50.5, R100.1, U124.13
!RESET!25: J52.5, R104.1, U129.13
!RESET!26: J54.5, R108.1, U134.13
!RESET!27: J56.5, R112.1, U139.13
!RESET!28: J58.5, R116.1, U144.13
!RESET!29: J60.5, R120.1, U149.13
!RESET!30: J62.5, R124.1, U154.13
!RESET!31: J64.5, R128.1, U159.13
!RESET!32: J66.5, R132.1, U164.13
!RESET!33: J68.5, R136.1, U169.13
!RESET!34: J70.5, R140.1, U174.13
!RESET!35: J72.5, R144.1, U179.13
!RESET!36: J74.5, R148.1, U184.13
!RESET!37: J76.5, R152.1, U189.13
!RESET!38: J78.5, R156.1, U194.13
!RESET!39: J80.5, R160.1, U199.13
!RESET!40: J82.5, R164.1, U204.13
!RESET!41: J84.5, R168.1, U209.13
!RESET!42: J86.5, R172.1, U214.13
!RESET!43: J88.5, R176.1, U219.13
!RESET!44: J90.5, R180.1, U224.13
!RESET!45: J92.5, R184.1, U229.13
!RESET!46: J94.5, R188.1, U234.13
!RESET!47: J96.5, R192.1, U239.13
AT_CIPO: J3.1, U5.20
AT_CIPO1: J4.1, U9.20
AT_CIPO2: J6.1, U14.20
AT_CIPO3: J8.1, U19.20
AT_CIPO4: J10.1, U24.20
AT_CIPO5: J12.1, U29.20
AT_CIPO6: J14.1, U34.20
AT_CIPO7: J16.1, U39.20
AT_CIPO8: J18.1, U44.20
AT_CIPO9: J20.1, U49.20
AT_CIPO10: J22.1, U54.20
AT_CIPO11: J24.1, U59.20
AT_CIPO12: J26.1, U64.20
AT_CIPO13: J28.1, U69.20
AT_CIPO14: J30.1, U74.20
AT_CIPO15: J32.1, U79.20
AT_CIPO16: J34.1, U84.20
AT_CIPO17: J36.1, U89.20
AT_CIPO18: J38.1, U94.20
AT_CIPO19: J40.1, U99.20
AT_CIPO20: J42.1, U104.20
AT_CIPO21: J44.1, U109.20
AT_CIPO22: J46.1, U114.20
AT_CIPO23: J48.1, U119.20
AT_CIPO24: J50.1, U124.20
AT_CIPO25: J52.1, U129.20
AT_CIPO26: J54.1, U134.20
AT_CIPO27: J56.1, U139.20
AT_CIPO28: J58.1, U144.20
AT_CIPO29: J60.1, U149.20
AT_CIPO30: J62.1, U154.20
AT_CIPO31: J64.1, U159.20
AT_CIPO32: J66.1, U164.20
AT_CIPO33: J68.1, U169.20
AT_CIPO34: J70.1, U174.20
AT_CIPO35: J72.1, U179.20
AT_CIPO36: J74.1, U184.20
AT_CIPO37: J76.1, U189.20
AT_CIPO38: J78.1, U194.20
AT_CIPO39: J80.1, U199.20
AT_CIPO40: J82.1, U204.20
AT_CIPO41: J84.1, U209.20
AT_CIPO42: J86.1, U214.20
AT_CIPO43: J88.1, U219.20
AT_CIPO44: J90.1, U224.20
AT_CIPO45: J92.1, U229.20
AT_CIPO46: J94.1, U234.20
AT_CIPO47: J96.1, U239.20
AT_VCC: C7.1, C8.1, J3.2, R4.2, U1.5, U5.9
AT_VCC1: C14.1, C16.1, J4.2, R8.2, U9.9, U10.5
AT_VCC2: C22.1, C24.1, J6.2, R12.2, U14.9, U15.5
AT_VCC3: C30.1, C32.1, J8.2, R16.2, U19.9, U20.5
AT_VCC4: C38.1, C40.1, J10.2, R20.2, U24.9, U25.5
AT_VCC5: C46.1, C48.1, J12.2, R24.2, U29.9, U30.5
AT_VCC6: C54.1, C56.1, J14.2, R28.2, U34.9, U35.5
AT_VCC7: C62.1, C64.1, J16.2, R32.2, U39.9, U40.5
AT_VCC8: C70.1, C72.1, J18.2, R36.2, U44.9, U45.5
AT_VCC9: C78.1, C80.1, J20.2, R40.2, U49.9, U50.5
AT_VCC10: C86.1, C88.1, J22.2, R44.2, U54.9, U55.5
AT_VCC11: C94.1, C96.1, J24.2, R48.2, U59.9, U60.5
AT_VCC12: C102.1, C104.1, J26.2, R52.2, U64.9, U65.5
AT_VCC13: C110.1, C112.1, J28.2, R56.2, U69.9, U70.5
AT_VCC14: C118.1, C120.1, J30.2, R60.2, U74.9, U75.5
AT_VCC15: C126.1, C128.1, J32.2, R64.2, U79.9, U80.5
AT_VCC16: C134.1, C136.1, J34.2, R68.2, U84.9, U85.5
AT_VCC17: C142.1, C144.1, J36.2, R72.2, U89.9, U90.5
AT_VCC18: C150.1, C152.1, J38.2, R76.2, U94.9, U95.5
AT_VCC19: C158.1, C160.1, J40.2, R80.2, U99.9, U100.5
AT_VCC20: C166.1, C168.1, J42.2, R84.2, U104.9, U105.5
AT_VCC21: C174.1, C176.1, J44.2, R88.2, U109.9, U110.5
AT_VCC22: C182.1, C184.1, J46.2, R92.2, U114.9, U115.5
AT_VCC23: C190.1, C192.1, J48.2, R96.2, U119.9, U120.5
AT_VCC24: C198.1, C200.1, J50.2, R100.2, U124.9, U125.5
AT_VCC25: C206.1, C208.1, J52.2, R104.2, U129.9, U130.5
AT_VCC26: C214.1, C216.1, J54.2, R108.2, U134.9, U135.5
AT_VCC27: C222.1, C224.1, J56.2, R112.2, U139.9, U140.5
AT_VCC28: C230.1, C232.1, J58.2, R116.2, U144.9, U145.5
AT_VCC29: C238.1, C240.1, J60.2, R120.2, U149.9, U150.5
AT_VCC30: C246.1, C248.1, J62.2, R124.2, U154.9, U155.5
AT_VCC31: C254.1, C256.1, J64.2, R128.2, U159.9, U160.5
AT_VCC32: C262.1, C264.1, J66.2, R132.2, U164.9, U165.5
AT_VCC33: C270.1, C272.1, J68.2, R136.2, U169.9, U170.5
AT_VCC34: C278.1, C280.1, J70.2, R140.2, U174.9, U175.5
AT_VCC35: C286.1, C288.1, J72.2, R144.2, U179.9, U180.5
AT_VCC36: C294.1, C296.1, J74.2, R148.2, U184.9, U185.5
AT_VCC37: C302.1, C304.1, J76.2, R152.2, U189.9, U190.5
AT_VCC38: C310.1, C312.1, J78.2, R156.2, U194.9, U195.5
AT_VCC39: C318.1, C320.1, J80.2, R160.2, U199.9, U200.5
AT_VCC40: C326.1, C328.1, J82.2, R164.2, U204.9, U205.5
AT_VCC41: C334.1, C336.1, J84.2, R168.2, U209.9, U210.5
AT_VCC42: C342.1, C344.1, J86.2, R172.2, U214.9, U215.5
AT_VCC43: C350.1, C352.1, J88.2, R176.2, U219.9, U220.5
AT_VCC44: C358.1, C360.1, J90.2, R180.2, U224.9, U225.5
AT_VCC45: C366.1, C368.1, J92.2, R184.2, U229.9, U230.5
AT_VCC46: C374.1, C376.1, J94.2, R188.2, U234.9, U235.5
AT_VCC47: C382.1, C384.1, J96.2, R192.2, U239.9, U240.5
CHG_LED: R1.1, U2.1
CHG_LED1: R5.1, U6.1
CHG_LED2: R9.1, U11.1
CHG_LED3: R13.1, U16.1
CHG_LED4: R17.1, U21.1
CHG_LED5: R21.1, U26.1
CHG_LED6: R25.1, U31.1
CHG_LED7: R29.1, U36.1
CHG_LED8: R33.1, U41.1
CHG_LED9: R37.1, U46.1
CHG_LED10: R41.1, U51.1
CHG_LED11: R45.1, U56.1
CHG_LED12: R49.1, U61.1
CHG_LED13: R53.1, U66.1
CHG_LED14: R57.1, U71.1
CHG_LED15: R61.1, U76.1
CHG_LED16: R65.1, U81.1
CHG_LED17: R69.1, U86.1
CHG_LED18: R73.1, U91.1
CHG_LED19: R77.1, U96.1
CHG_LED20: R81.1, U101.1
CHG_LED21: R85.1, U106.1
CHG_LED22: R89.1, U111.1
CHG_LED23: R93.1, U116.1
CHG_LED24: R97.1, U121.1
CHG_LED25: R101.1, U126.1
CHG_LED26: R105.1, U131.1
CHG_LED27: R109.1, U136.1
CHG_LED28: R113.1, U141.1
CHG_LED29: R117.1, U146.1
CHG_LED30: R121.1, U151.1
CHG_LED31: R125.1, U156.1
CHG_LED32: R129.1, U161.1
CHG_LED33: R133.1, U166.1
CHG_LED34: R137.1, U171.1
CHG_LED35: R141.1, U176.1
CHG_LED36: R145.1, U181.1
CHG_LED37: R149.1, U186.1
CHG_LED38: R153.1, U191.1
CHG_LED39: R157.1, U196.1
CHG_LED40: R161.1, U201.1
CHG_LED41: R165.1, U206.1
CHG_LED42: R169.1, U211.1
CHG_LED43: R173.1, U216.1
CHG_LED44: R177.1, U221.1
CHG_LED45: R181.1, U226.1
CHG_LED46: R185.1, U231.1
CHG_LED47: R189.1, U236.1
CIPO: IN.6, OUT.6
CIPO1: IN1.6, OUT1.6
CIPO2: IN2.6, OUT2.6
CIPO3: IN3.6, OUT3.6
CIPO4: IN4.6, OUT4.6
CIPO5: IN5.6, OUT5.6
CIPO6: IN6.6, OUT6.6
CIPO7: IN7.6, OUT7.6
CIPO8: IN8.6, OUT8.6
CIPO9: IN9.6, OUT9.6
CIPO10: IN10.6, OUT10.6
CIPO11: IN11.6, OUT11.6
CIPO12: IN12.6, OUT12.6
CIPO13: IN13.6, OUT13.6
CIPO14: IN14.6, OUT14.6
CIPO15: IN15.6, OUT15.6
CIPO16: IN16.6, OUT16.6
CIPO17: IN17.6, OUT17.6
CIPO18: IN18.6, OUT18.6
CIPO19: IN19.6, OUT19.6
CIPO20: IN20.6, OUT20.6
CIPO21: IN21.6, OUT21.6
CIPO22: IN22.6, OUT22.6
CIPO23: IN23.6, OUT23.6
CIPO24: IN24.6, OUT24.6
CIPO25: IN25.6, OUT25.6
CIPO26: IN26.6, OUT26.6
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

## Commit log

2021-05-17 Partially routed
    [SparkX_EZ_LiPo_Power.brd, SparkX_EZ_LiPo_Power.sch]
2021-05-17 Freshly routed
    [SparkX_EZ_LiPo_Power.brd, SparkX_EZ_LiPo_Power.sch]
2021-05-18 Ready for review
    [SparkX_EZ_LiPo_Power-Panel.GBL, SparkX_EZ_LiPo_Power-Panel.GBO, SparkX_EZ_LiPo_Power-Panel.GBP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]
2021-05-25 Post-review updates
    [SparkX_EZ_LiPo_Power-Panel.GBL, SparkX_EZ_LiPo_Power-Panel.GBO, SparkX_EZ_LiPo_Power-Panel.GBP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]
2021-05-26 Final tweaks
    [SparkX_EZ_LiPo_Power-Panel.brd, SparkX_EZ_LiPo_Power.brd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]
2021-05-27 Gapless production panel
    [SparkX_EZ_LiPo_Power-Panel.brd, SparkX_EZ_LiPo_Power.brd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]
2021-06-09 Update 16-way FPC Connector. Add missing PROD_IDs
    [SparkX_EZ_LiPo_Power.brd, SparkX_EZ_LiPo_Power.sch]
2021-08-02 Correcting I2C restart-after-power-down problems
2021-08-18 X02 - changed to smol branding
    [SparkX_EZ_LiPo_Power-Panel.brd, SparkX_EZ_LiPo_Power.brd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]
2021-08-19 Update smol symbol
    [SparkX_smol_LiPo_Power-Panel.brd, SparkX_smol_LiPo_Power.brd, SparkX_smol_LiPo_Power.sch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]
2021-08-20 Change EZ to smôl on schematic
    [SparkX_smol_LiPo_Power.sch]

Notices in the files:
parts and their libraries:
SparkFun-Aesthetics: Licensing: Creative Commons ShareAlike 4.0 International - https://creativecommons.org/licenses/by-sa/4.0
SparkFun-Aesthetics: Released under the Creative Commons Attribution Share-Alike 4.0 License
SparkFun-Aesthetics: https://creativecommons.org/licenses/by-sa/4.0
